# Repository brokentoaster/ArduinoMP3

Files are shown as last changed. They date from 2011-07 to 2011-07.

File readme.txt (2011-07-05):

The Arduino MP3 shield is an add on board for developing Arduino based systems that incorporate MP3 decoding, SD cards and Joysticks. It is initially based on the work done as part of the ButterflyMP3 Project.

For more details please see http://www.brokentoaster.com/arduinomp3/

Arduino MP3 Shield hardware by Nick Lott is licensed under a Creative Commons Attribution-Share Alike 2.0 UK: England & Wales License	

The Arduino MP3 Shield firmware is licensed under a GNU GPL v2.0 License. It is a derivative of the Butterfly MP3 project at http://www.brokentoaster.com/butterflymp3/

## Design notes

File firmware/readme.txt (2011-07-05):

To use this library for Arduino please copy into the "libraries" directory in your "sketchbook" or "arduino" directory

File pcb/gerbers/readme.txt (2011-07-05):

Files:
===================================================
 readme.txt			This file.
 ArduinoMp3Shield.cmp		Top Copper layer
 ArduinoMp3Shield.drd		Drill file (NC Excellon format)
 ArduinoMp3Shield.dri		Drill file information (text format)
 ArduinoMp3Shield.plc		Top Silkscreen
 ArduinoMp3Shield.sol		Bottom Copper layer
 ArduinoMp3Shield.stc		Top Layer Solder mask 
 ArduinoMp3Shield.sts		Bottom Layer Solder mask

Physical Details:
===================================================
Total PCB size: X = 68.58mm Y = 53.34mm
Base material: FR4, 35µmCu, 1,6mm
Soldermask: yes, both sides.
Position print / Silkscreen: yes, TOP only

Gerber file details:
===================================================

Generated by EAGLE CAM Processor 5.7.0

Photoplotter Info File: /Users/nick/Perforce/mini_1666/nick_MacBook/ArduinoMP3/working/pcb/ArduinoMp3Shield.gpi

 Date              : 15/02/2010 10:09PM
 Plotfile          : /Users/nick/Perforce/mini_1666/nick_MacBook/ArduinoMP3/working/pcb/ArduinoMp3Shield.sts
 Apertures         : generated: 
 Device            : Gerber RS-274-X photoplotter, coordinate format 2.4 inch

Parameter settings:

 Emulate Apertures : no
 Emulate Thermal   : no
 Emulate Annulus   : no
 Tolerance Draw  + :  0.00 %
 Tolerance Draw  - :  0.00 %
 Tolerance Flash + :  0.00 %
 Tolerance Flash - :  0.00 %
 Rotate            : no
 Mirror            : no
 Optimize          : yes
 Auto fit          : yes
 OffsetX           : 0inch
 OffsetY           : 0inch

Plotfile Info:

 Coordinate Format : 2.4
 Coordinate Units  : Inch
 Data Mode         : Absolute
 Zero Suppression  : None
 End Of Block      : *

Apertures used:

 Code     Shape     Size                  used

 D10      octagon   0.0710inch               2
 D11      round     0.0710inch               2
 D12      round     0.1307inch               2
 D13      round     0.0966inch               2
 D14      round     0.0375inch               1
 D15      round     0.0493inch               1
 D16      round     0.0710inch               1
 D17      round     0.0552inch               1
 D18      octagon   0.0680inch               3
 D19      draw      0.0680inch              28
 D20      round     0.0480inch              51
 D21      round     0.0671inch              35

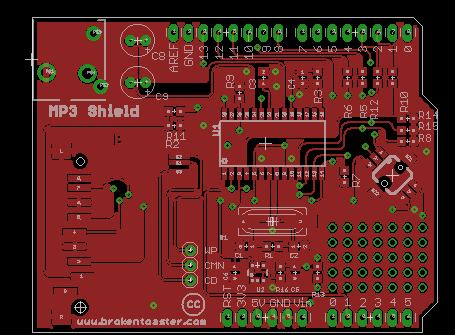
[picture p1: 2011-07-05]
files/rev_b/top.png

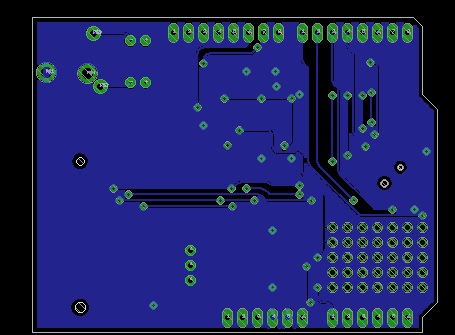
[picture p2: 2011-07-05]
files/rev_b/bot.png

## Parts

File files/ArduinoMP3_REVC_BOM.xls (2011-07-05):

Name | Qty | Value | Device | Manufacturer | Manufcturers Part No | Farnell Equivalent | Digikey Equivalent
ANALOG, POWER | 2 |  | Header 0.1" 1x6 | Generic | 0.1" pin header 6 Way | 1022255 | WM6406-ND
C1, C2 | 2 | 33pF | Capacitor SMD | Generic | 5% 0805 50V | 1362559 | PCC1961CT-ND
C3, C4 | 2 | 0.1uF | Capacitor SMD | Generic Y5V | 20% 0805 50V | 9406409 | PCC1828CT-ND
C5, C6 | 2 | 2.2uF | Capacitor SMD | Generic Y5V | 20% 0805 50V | 9527702 | PCC2320CT-ND
C8, C9 | 2 | 100uF | Capacitor Electrolytic, 5-6mm radial, 5-6mm hieght, 2.54mm Pitch | Generic Electrolytic | 20% Radial 6.3V | 9452176 | MCUMR6V3107M5X5
CD, CMN, WP | 3 | NOT FITTED | Test Point
DIGITAL_0_7, DIGITAL_8_13 | 2 |  | Header 0.1" 1x8 | Generic | 0.1" pin header 8 Way | 1022257 | WM6408-ND
HDPHN | 1 |  | 3.5mm PCB Mount Stero Jack | Schurter | 4832.232 | 152204 | CP-3504-ND
MMC1 | 1 |  | MMC_SW | Multicomp | SDAMB-01215BT00 | 9186140
Q1 | 1 | 12.288MHz | CRYSTALHC49UP | Abracon | ABLS-12.288MHZ-B2-T | 1611787 | 535-9068-1-ND
R1 | 1 | 1 Meg | Resistor, SMD | Generic | 0.1W 0805 5% | 9333746 | 541-1.00MCCT-ND
R16 | 1 | 1R | Resistor, SMD | Generic | 0.1W 0805 5% | 9237127 | 541-1.00CCT-ND
R2, R3, R7, R8, R9, R14, R15 | 7 | 10K | Resistor, SMD | Generic | 0.1W 0805 5% | 9333720 | 541-10.0KCCT-ND
R5, R6, R10, R11, R12, R13 | 6 | 4K7 | Resistor, SMD | Generic | 0.1W 0805 5% | 9237704 | 541-4.70KCCT-ND
S1 | 1 |  | 5-Way SMD Joystick | Multicomp | MCMT5-F-V | 1316987
U1 | 1 | VS1011E | VS1011E-S MP3 CODEC | VLSI Oy (www.vlsi.fi) | VS1011E-S
U2 | 1 | LP2981-3.3 | LP2981 3.3V LDO REG | National Semiconductor | LP2981AIM5-3.3/NOPB | 1469129 | LP2981AIM5-3.3CT-ND
PCB | 1 |  | PCB REVC | Gold Phoenix

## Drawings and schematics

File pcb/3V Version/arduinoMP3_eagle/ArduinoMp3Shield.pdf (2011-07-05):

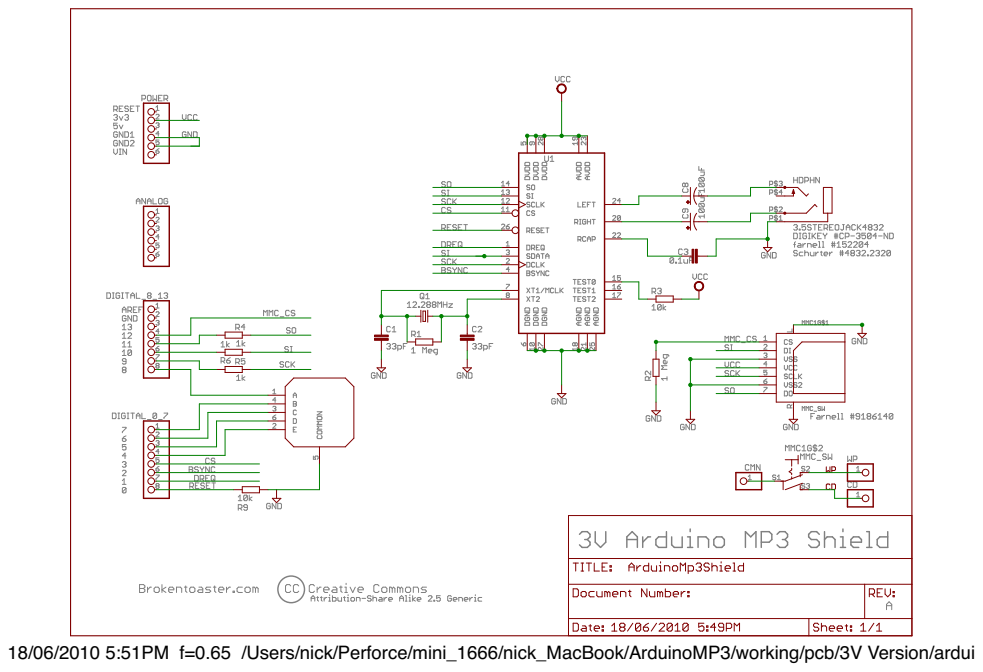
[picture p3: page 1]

18/06/2010 5:51PM f=0.65 /Users/nick/Perforce/mini_1666/nick_MacBook/ArduinoMP3/working/pcb/3V Version/ardui

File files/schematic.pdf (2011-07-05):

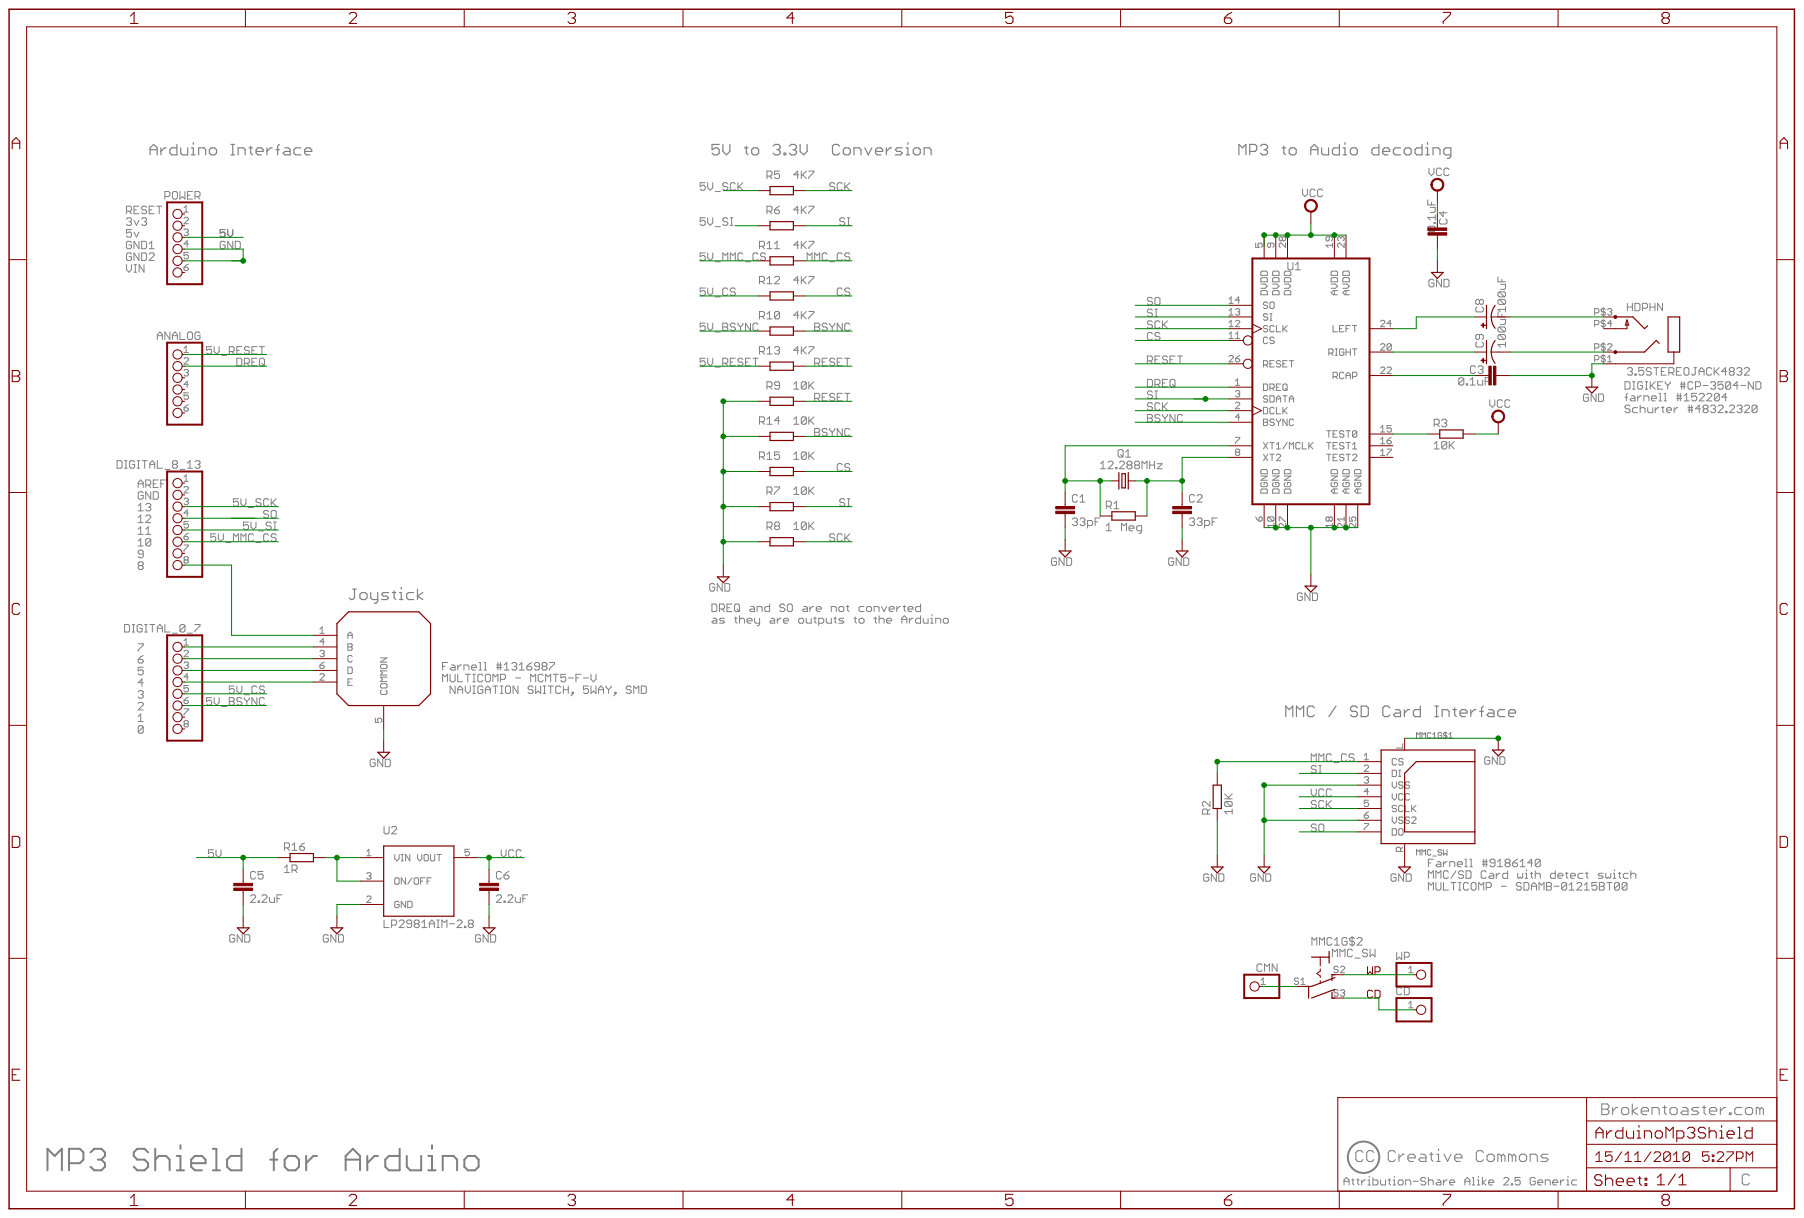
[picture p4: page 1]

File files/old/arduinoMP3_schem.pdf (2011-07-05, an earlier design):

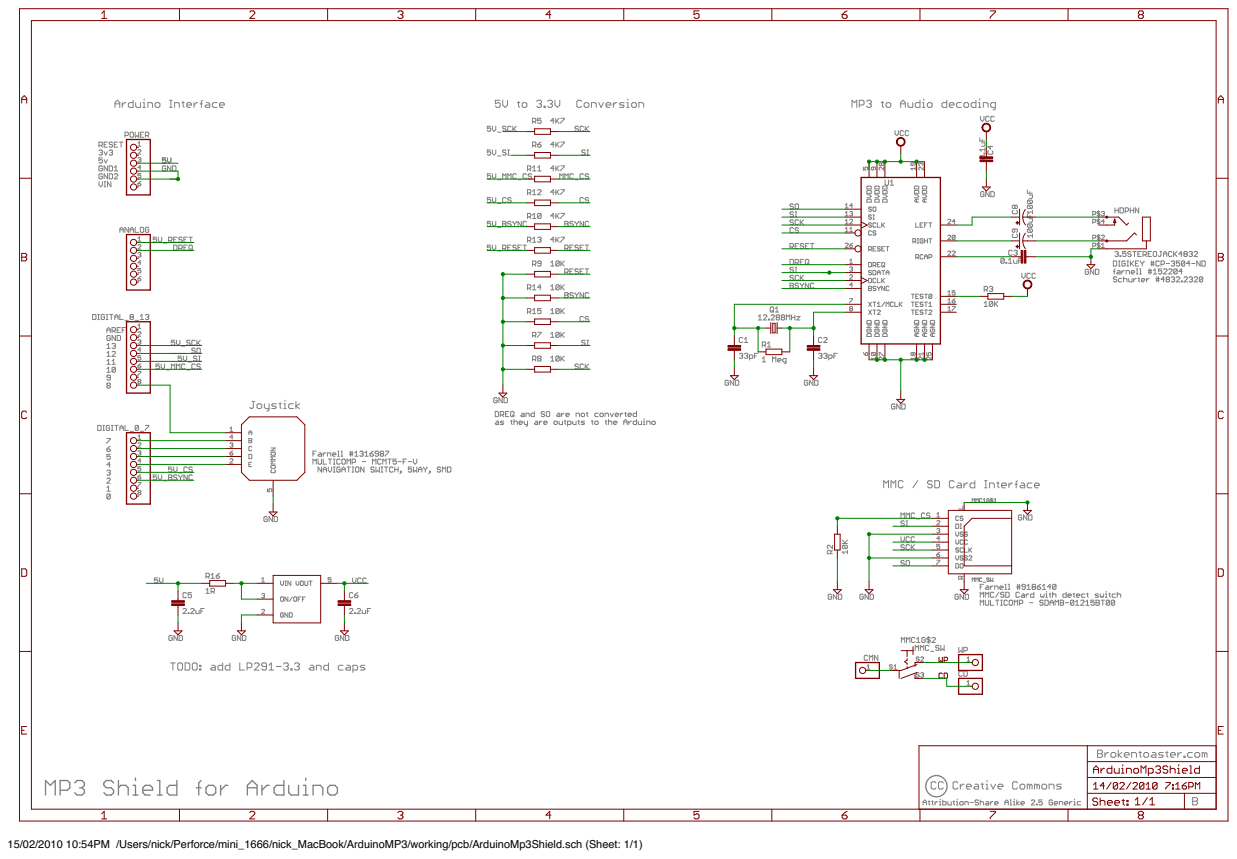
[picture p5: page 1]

15/02/2010 10:54PM /Users/nick/Perforce/mini_1666/nick_MacBook/ArduinoMP3/working/pcb/ArduinoMp3Shield.sch (Sheet: 1/1)

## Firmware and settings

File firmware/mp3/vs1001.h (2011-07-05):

/**
	@file	vs1001.h
	@brief	VS1001 interface library
	@author	Jesper Hansen 
	@date	2000
 
	$Id: vs1001.h,v 1.6 2009/01/10 22:38:51 brokentoaster Exp $
 
 Copyright (C) 2000 Jesper Hansen <jesperh@telia.com>.
 
 This file is part of the yampp system.
 
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
 You should have received a copy of the GNU General Public License
 along with this program; if not, write to the Free Software Foundation, 
 Inc., 59 Temple Place - Suite 330, Boston, MA  02111-1307, USA.
 **/

/* 
 * Modified for Arduino MP3 30/12/2009	
 */
#ifndef __VS1001_H
#define __VS1001_H

#define DREQ_DDR	DDRC
#define BSYNC_DDR	DDRD    
#define xDCS_DDR	DDRD 
#define MP3_DDR		DDRD
#define RESET_DDR	DDRC

#define DREQ_PORT	PINC
#define BSYNC_PORT	PORTD    
#define xDCS_PORT	PORTD    
#define MP3_PORT	PORTD
#define RESET_PORT	PORTC

#define DREQ_PIN	1				// DREQ signal
#define	BSYNC_PIN	2				// BSYNC signal
#define	xDCS_PIN	2				// xDCS signal (new mode)
#define MP3_PIN		3				// MP3 control bit
#define RESET_PIN	0				// -RESET signal

//TODO: add code to use SCI_STATUS to determine 

#define VS1000_NEW					// Use the new mode for VS1053 and newer
//#define VS1001
#define VS1011
//#define VS1053


// defines for Mode control of vs1001k
#ifdef VS1001
#define SM_DIFF 	1
#define SM_FFWD 	2
#define SM_RESET 	4
#define SM_MP12 	8
#define SM_PDOWN 	16
#define SM_DAC 		32
#define SM_DACMONO 	64
#define SM_BASS 	128
#define SM_DACT 	256
#define SM_IBMODE	512
#define SM_IBCLK	1024
#endif

#ifdef VS1011            //Bit  Function Value Description 
#define SM_DIFF         (1<<0)  //  Differential 0 normal in-phase audio 1 left channel inverted 
#define SM_LAYER12      (1<<1)  //  Allow MPEG layers I & II 0 no 1 yes 
#define SM_RESET        (1<<2)  //  Soft reset 0 no reset 1 reset 
#define SM_OUTOFWAV     (1<<3)  //  Jump out of WAV decoding 0 no 1 yes 
#define SM_SETTOZERO1   (1<<4)  //  set to zero 0 right 1 wrong 
#define SM_TESTS        (1<<5)  //  Allow SDI tests 0 not allowed 1 allowed 
#define SM_STREAM       (1<<6)  //  Stream mode 0 no 1 yes 
#define SM_SETTOZERO2   (1<<7)  //  set to zero 0 right 1 wrong 
#define SM_DACT         (1<<8)  //  DCLK active edge 0 rising 1 falling 
#define SM_SDIORD       (1<<9)  //  SDI  bit order 0 MSb ﬁrst 1 MSb last 
#define SM_SDISHARE     (1<<10) //  Share SPI chip select 0 no 1 yes 
#define SM_SDINEW       (1<<11) //  VS1002 native SPI modes 0 no 1 yes 
#define SM_SETTOZERO3   (1<<12) //  set to zero 0 right 1 wrong 
#define SM_SETTOZERO4   (1<<13) //  set to zero 0 right 1 wrong 
#endif 

#ifdef VS1053            //Bit  Function Value Description 
#define SM_DIFF         (1<<0)  //  Differential 0 normal in-phase audio 1 left channel inverted 
#define SM_LAYER12      (1<<1)  //  Allow MPEG layers I & II 0 no 1 yes 
#define SM_RESET        (1<<2)  //  Soft reset 0 no reset 1 reset 
#define SM_CANCEL       (1<<3)  //  Cancel decoding current ﬁle 0 no 1 yes 
#define SM_EARSPEAKER_LO (1<<4) //  EarSpeaker low setting  0 off 1 active 
#define SM_TESTS        (1<<5)  //  Allow SDI tests 0 not allowed 1 allowed 
#define SM_STREAM       (1<<6)  //  Stream mode 0 no 1 yes 
#define SM_EARSPEAKER_HI (1<<7) //  EarSpeaker high setting  0 off 1 active 
#define SM_DACT         (1<<8)  //  DCLK active edge 0 rising 1 falling 
#define SM_SDIORD       (1<<9)  //  SDI  bit order 0 MSb ﬁrst 1 MSb last 
#define SM_SDISHARE     (1<<10) //  Share SPI chip select 0 no 1 yes 
#define SM_SDINEW       (1<<11) //  VS1002 native SPI modes 0 no 1 yes 
#define SM_ADPCM        (1<<12) //  ADPCM recording active 0 no 1 yes 
#define SM_LINE1        (1<<14) //  MIC / LINE1 selector 0 MICP 1 LINE1
#define SM_CLK_RANGE    (1<<15) //  Input clock range 0 12..13 MHz 
#endif

// defines for SCI registers
#ifdef VS1001
#define SCI_MODE		0
#define SCI_STATUS		1
#define SCI_INT_FCTLH	2
#define SCI_CLOCKF		3
#define SCI_DECODE_TIME 4
#define SCI_AUDATA		5
#define SCI_WRAM		6
#define SCI_WRAMADDR	7
#define SCI_HDAT0		8
#define SCI_HDAT1		9
#define SCI_AIADDR		10
#define SCI_VOL			11
#endif

#if defined (VS1011) || defined (VS1053)
//                      Reg           Type Reset Time1    Description 
#define SCI_MODE        0x0         // rw  0     70 CLKI4 Mode control 
#define SCI_STATUS      0x1         // rw  0x2C3 40 CLKI  Status of VS1011e 
#define SCI_BASS        0x2         // rw  0   2100 CLKI  Built-in bass/treble enhancer 
#define SCI_CLOCKF      0x3         // rw  0     80 XTALI Clock freq + multiplier 
#define SCI_DECODE_TIME 0x4         // rw  0     40 CLKI  Decode time in seconds 
#define SCI_AUDATA      0x5         // rw  0   3200 CLKI  Misc. audio data 
#define SCI_WRAM        0x6         // rw  0     80 CLKI  RAM write/read 
#define SCI_WRAMADDR    0x7         // rw  0     80 CLKI  Base address for RAM write/read 
#define SCI_HDAT0       0x8         // r   0       -      Stream header data 0 
#define SCI_HDAT1       0x9         // r   0       -      Stream header data 1 
#define SCI_AIADDR      0xA         // rw  0   3200 CLKI2 Start address of application 
#define SCI_VOL         0xB         // rw  0   2100 CLKI  Volume control 
#define SCI_AICTRL0     0xC         // rw  0     50 CLKI2 Application control register 0 
#define SCI_AICTRL1     0xD         // rw  0     50 CLKI2 Application control register 1 
#define SCI_AICTRL2     0xE         // rw  0     50 CLKI2 Application control register 2 
#define SCI_AICTRL3     0xF         // rw  0     50 CLKI2 Application control register 3
#endif

typedef enum {
	SOFT_RESET,
	HARD_RESET
} reset_e;

class vs1001
    {
    public:


    // setup I/O pins and directions for
    // communicating with the VS1001
    void init_io(void);

    // setup the VS1001 chip for decoding
    void init_chip(void);

    // reset the VS1001
    void reset(reset_e r);

    // send a number of zero's to the VS1001
    void nulls(unsigned int nNulls);

    void read(uint8 address, uint16 count, uint16 *pData);

    //
    // write one or more word(s) to the VS1001 Control registers
    //
    void write(uint8 address, uint16 count, uint16 *pData);

    void setvolume(unsigned char left, unsigned char right);

    // send MP3 data
    void send_data(unsigned char b);
    void send_32(unsigned char *p);

    // test with beeps
    void sine_test(void);
            
    };


#endif

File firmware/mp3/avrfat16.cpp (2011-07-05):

/**
	@file	avrfat16.c
	@brief	Fat16 Functions
	@author	Nick Lott 
	@date	September 2004
	
	$Id: avrfat16.c,v 1.30 2009/01/19 23:36:09 brokentoaster Exp $
 
	Copyright (C) 2004 Nick Lott <brokentoaster@users.sf.net>
 
	This is a simple implementation of the FAT16 file system. It is designed
	to be small for use with MP3 players and MMC cards. Currently it is 
	readonly.NOTE: The code acknowledges only the first partition on the drive.
	
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
 
	Target(s)...: ATmega169
 
	Compiler....: AVR-GCC 3.3.1; avr-libc 1.0
 
 **/

#ifndef __AVRFAT16_CPP_
#define __AVRFAT16_CPP_
#include "avrfat16.h"
#include "utils.h"

typedef unsigned char  u08;
typedef          char  s08;
typedef unsigned short u16;
typedef          short s16;
typedef unsigned long  u32;
typedef          long  s32;



void UART_SendByte(u08 Data)
{   
    /* wait for UART to become available */
	while ( (UCSR0A & (1<<UDRE0)) != (1<<UDRE0) ) ;
    
    /* Send character */
    UDR0 = Data;
}




void UART_PrintfU4(u08 Data)
{
    /* Send 4-bit hex value */
    u08 Character = Data&0x0f;
    if (Character>9)
    {
        Character+='A'-10;
    }
    else
    {
        Character+='0';
    }
    UART_SendByte(Character);
}

void UART_Printfu08(u08 Data)
{
    /* Send 8-bit hex value */
    UART_PrintfU4(Data>>4);
    UART_PrintfU4(Data);
}

void UART_Printfu16(u16 Data)
{
    /* Send 16-bit hex value */
    UART_Printfu08(Data>>8);
    UART_Printfu08(Data);
}

void UART_Printfu32(u32 Data)
{
    /* Send 32-bit hex value */
    UART_Printfu16(Data>>16);
    UART_Printfu16(Data);
}

/*****************************************************************************
 *
 *   Function name : strLen
 *
 *   @return       Length of string
 *
 *   Purpose :       Find the length of a string (excluding NULL char)
 *
 *****************************************************************************/
uint16 strLen(uint8 *str)
{
    uint16 len;
    
    for (len = 0; str[len] != 0x00; len++);
    
    return (len);
}

/*****************************************************************************
 *
 *   Function name : strCatChar
 *
 *   Purpose :       Append a byte to a string buffer
 *
 *****************************************************************************/
void strCatChar(uint8 *str, uint8 byte)
{
    uint16 len;
    
    len = strLen(str);
    str[len] = byte;
    str[len+1] = '\0';
}


//void FAT16::FAT_PrintRecord(uint8 *pRecord);



/**
 *   FAT16::FAT_initFat16
 *	@brief		read MBR and bootsector and set global fat variables
 *	@return 	non zero for error.
 **/
unsigned char FAT16::FAT_initFat16(void) 
{
	unsigned char 	result,type,lba_begin,sectors_per_cluster,number_of_fats;
	unsigned short	bytes_per_sector,number_of_reserved_sectors,BPB_RootEntCnt;
	unsigned short	sectors_per_fat;
	
	// Assume read and write routines have been setup and are not NULL :)
	
	// read the first sector (MBR)
	/*
	 check for 55 AA signature
	 Read Partition info at 
	 446+4 = type check it's a vfat etc
	 446+8..11 = LBA Begin
	 446+12..15 =# of Sectors
	 */
    gFAT_entry 	=0;
    
	result = FAT16::rawDev->read(0);
	
	if (result)
		return result; // abort on read error
	
	if (FAT16::FAT_buffer[510] != 0x55 || FAT16::FAT_buffer[511] != 0xAA)
		return 0xAA; // abort if signature bytes not found in MBR
	
	type = FAT16::FAT_buffer[PARTITION_START+4]; // get type code for partition one
	
	// TODO: check here for valid MMC types ie FAT16 = 0x
	
	// get start of FAT partition.
//	*((uint8 *)&lba_begin+3) = FAT16::FAT_buffer[PARTITION_START+11];
//	*((uint8 *)&lba_begin+2) = FAT16::FAT_buffer[PARTITION_START+10];
//	*((uint8 *)&lba_begin+1) = FAT16::FAT_buffer[PARTITION_START+9];
//	*((uint8 *)&lba_begin+0) = FAT16::FAT_buffer[PARTITION_START+8];
	
	lba_begin = FAT16::FAT_buffer[PARTITION_START+11];
	lba_begin <<=8;	
	lba_begin += FAT16::FAT_buffer[PARTITION_START+10];
	lba_begin <<=8;	
	lba_begin += FAT16::FAT_buffer[PARTITION_START+9];
	lba_begin <<=8;	
	lba_begin += FAT16::FAT_buffer[PARTITION_START+8];
	
	
	/*	Read Boot Sector at lba Begin
		bytes_per_sector at 0x0B
		sectors_per_cluster at 0x0D
		number_of_reserved_sectors at 0x0E
		number_of_fats	at 0x10
		secters_per_fat at 0x24
		root_director_first_sector 0x2c
		*/
	
	// read FAT Volume ID
	result = FAT16::rawDev->read(lba_begin);
	if (result) return result; // abort on read error
	
	//if (FAT16::FAT_buffer[510] != 0x55 || FAT16::FAT_buffer[511] != 0xAA)
	//	return 0xAA; // abort if signature bytes not found in MBR
	
	
	sectors_per_cluster= FAT16::FAT_buffer[0x0D];
	PRINT("SECTORS PER CLUSTOR ");UART_Printfu08(sectors_per_cluster);EOL();
	
	number_of_reserved_sectors = FAT16::FAT_buffer[ 0x0f];
	number_of_reserved_sectors <<=8;
	number_of_reserved_sectors += FAT16::FAT_buffer[ 0x0e];
	
	number_of_fats = FAT16::FAT_buffer[0x10];
	
	bytes_per_sector = FAT16::FAT_buffer[0x0c];
	bytes_per_sector <<=8;
	bytes_per_sector += FAT16::FAT_buffer[0x0b];
	
	PRINT("BYTES PERSECTOR ");UART_Printfu16(bytes_per_sector);EOL();
	
	// BPB_FATSz16
	sectors_per_fat = FAT16::FAT_buffer[0x17];
	sectors_per_fat <<=8;
	sectors_per_fat += FAT16::FAT_buffer[0x16];
	
	//BPB_RootEntCnt
	BPB_RootEntCnt = FAT16::FAT_buffer[0x12];
	BPB_RootEntCnt <<=8;
	BPB_RootEntCnt += FAT16::FAT_buffer[0x11];
	
	
	/*
	 FOR FAT32....
	 sectors_per_fat = FAT16::FAT_buffer[0x27];
	 sectors_per_fat <<=8;
	 sectors_per_fat += FAT16::FAT_buffer[0x26];
	 sectors_per_fat <<=8;
	 sectors_per_fat += FAT16::FAT_buffer[0x25];
	 sectors_per_fat <<=8;
	 sectors_per_fat += FAT16::FAT_buffer[0x24];
	 
	 root_director_first_sector = FAT16::FAT_buffer[0x2f];
	 root_director_first_sector <<=8;
	 root_director_first_sector += FAT16::FAT_buffer[0x2e];
	 root_director_first_sector <<=8;
	 root_director_first_sector += FAT16::FAT_buffer[0x2d];
	 root_director_first_sector <<=8;
	 root_director_first_sector += FAT16::FAT_buffer[0x2c];
	 */
	
	// note: FAT16 clusters start after root directory.
  FAT16::FAT16_fat_begin_lba = lba_begin + number_of_reserved_sectors;
  FAT16::FAT16_root_dir_first_sector = FAT16::FAT16_fat_begin_lba + ( number_of_fats * sectors_per_fat);
  FAT16::FAT16_cluster_begin_lba = FAT16::FAT16_root_dir_first_sector+
		((BPB_RootEntCnt*32) + (bytes_per_sector-1))/bytes_per_sector;
	//	((BPB_RootEntCnt*32) + (bytes_per_sector))/bytes_per_sector;
  FAT16::FAT16_sectors_per_cluster = sectors_per_cluster;
	
  FAT16::FAT16_dir_first_sector=FAT16_root_dir_first_sector;
  FAT16::FAT16_parent_dir_first_sector = FAT16::FAT16_root_dir_first_sector;
	
	return 0;
}

/**
*   FAT16::FAT_get_label
 *	@brief		copys the volume label
 *	@param		destentaion for label
 *	@return 	non zero for error.
 **/
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

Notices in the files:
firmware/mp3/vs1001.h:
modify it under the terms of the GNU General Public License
